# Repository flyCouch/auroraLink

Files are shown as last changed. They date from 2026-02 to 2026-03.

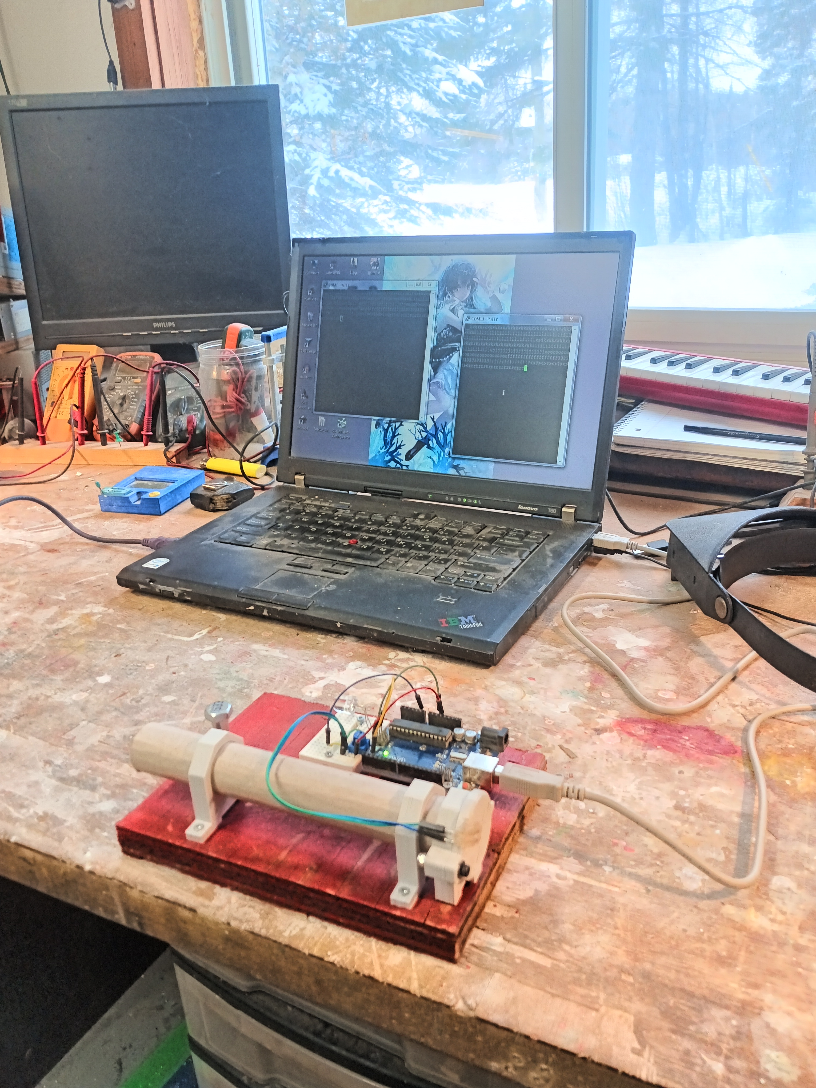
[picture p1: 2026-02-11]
pics/50cm_IMG_20260211_154655028.jpg

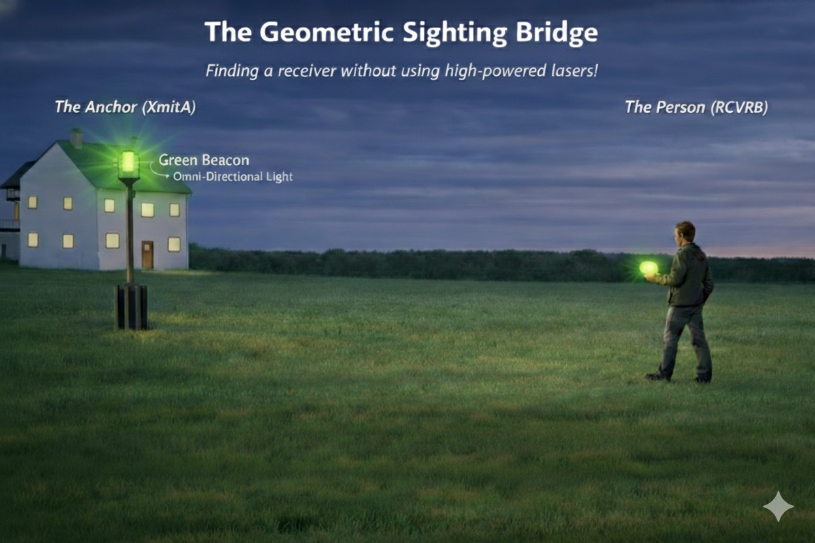
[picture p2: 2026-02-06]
pics/greenGlobes2.png

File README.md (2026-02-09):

A light based Bulletin Board System.

Aurora-Link: The Optical BBS Anchor (v3.3)
Aurora-Link is a human-scale, line-of-sight data bridge designed to provide local community connectivity without relying on radio frequencies or traditional ISPs. By combining 1200-baud optical telescopes with the power of Synchronet BBS, this system creates a secure, "Geometric Bridge" between a home anchor and a mobile visitor.

📡 The Hardware Stack

The Brain: A legacy Windows 7 (32-bit) laptop running Synchronet v3. 

The Optical Interface: An Arduino-controlled 525nm Green LED (Beacon) and a CdS photoresistor sensor. 

The Sight: Dual telescopes mounted on 3D-printed PLA Picatinny rails for rigid, repeatable manual alignment.

The Receiver: A single-potentiometer voltage divider on Analog Pin A0 that allows hardware-level sensitivity tuning for varying ambient light conditions. 

🛠️ The "Self-Healing" .ino Logic
The firmware serves as a "Smart Bridge" with three core modes:

Sighting Mode: The system defaults to a steady Green Beacon, acting as a lighthouse to guide visitors for manual telescope alignment. 

Data Mode: Upon detecting serial activity from the PC or incoming light from a visitor, the system instantly switches to 1200-baud data transmission. 

Self-Healing: If the link is silent for 15 seconds, the system automatically reverts to a steady beacon, allowing for easy re-alignment if a telescope is bumped. 

Manual Override: Sending a !!! command via the Serial terminal forces the system back into Sighting Mode immediately. 

🏠 The Steward Philosophy
Eco-Friendly: Constructed using food-grade, UV-stabilized PLA to ensure long-term environmental safety.

Safe & Precise: Uses low-power LEDs instead of high-powered lasers, making it safe for eyes, neighbors, and local wildlife.

Zero RF Footprint: Operates entirely on the visible light spectrum, eliminating radio interference in the neighborhood.

🚀 Getting Started
Mount your telescopes to the Picatinny rail system.

Install Synchronet to C:\SBBS on a Windows 7 machine. Or be a client.

Upload the AuroraLink15.ino (or latest) to your Arduino.

Align the telescopes until the signal LED (Pin 13) locks on.

Enter the BBS and join the local conversation.

🖥️ Connecting via Terminal (Minicom / PuTTY)
While Synchronet handles the backend BBS logic, you can interact with the Aurora-Link hardware directly using a terminal emulator. This is ideal for initial signal testing or "handshaking" with the anchor.

1. Terminal Configuration
To communicate with the Arduino "Modem," set your terminal to the following parameters:

Speed (Baud): 1200 

Data Bits: 8

Parity: None

Stop Bits: 1

Flow Control: None (XON/XOFF disabled)

2. Using Minicom (Linux/macOS)
Launch Minicom with the following command (replacing ttyUSB0 with your actual port):

Bash

minicom -b 1200 -D /dev/ttyUSB0
To Re-align: Type !!! and press Enter. The "Self-Healing" logic will detect this string and force the Green Beacon to stay solid for 15 seconds, giving you time to adjust your telescope.

3. Using PuTTY (Windows 7)
Select Serial as the connection type.

Enter your COM Port (e.g., COM3).

Set Speed to 1200.

I’ve added the Minicom/Terminal section you requested to the summary. This explains how to use standard tools to interact with the Aurora-Link hardware.

Connecting via Terminal (Minicom / Tera Term)
While Synchronet handles the BBS backend, you can use terminal emulators to interact with the hardware "handshake" directly.

Serial Settings: 1200 Baud, 8-N-1, No Flow Control.

The "!!!" Command: Typing !!! followed by Enter sends a force-reset to the Arduino. The "Self-Healing" logic detects this string and locks the Green Beacon into a solid state for 15 seconds, allowing you to re-align your telescopes manually.

Signal Monitoring: In Minicom, you will see a stream of '1's and '0's when light is detected by the voltage divider, giving you real-time feedback on your link quality.

Synchronet Configuration (SCFG)
Once your circuit is tucked into those new bases, here is how to tell Synchronet to listen to your laptop's serial port:

Open SCFG.exe.

Go to Nodes -> Node 1 -> Hardware/UART Settings.

Set the COM Port to match your Arduino (e.g., COM3).

Set the Baud Rate to 1200.

Set Command Line to *INTERNAL.

This maps the physical optical pulses coming into your Windows 7 laptop directly to the BBS login screen.

Under the Terminal category, ensure "Implicit CR in every LF" is checked to keep the BBS text scrolling cleanly.

A Quick Tip for Windows 7:
Since you are using a 32-bit laptop, if you find that Minicom is a bit too "Linux-heavy" for your field tests, Tera Term is a fantastic, lightweight alternative for Windows 7. It handles the 1200-baud stream very gracefully and makes it easy to log your "Geometric Bridge" signal strength tests to a text file.

Operational Modes
Sighting Mode (Beacon): A steady green LED allows for manual alignment between nodes.

Data Mode: Automatically engages upon serial or optical activity, transmitting data via light pulses.

Self-Healing: Automatically reverts to Beacon mode after 15 seconds of silence to assist in recovering a lost connection.

Hard Disable (Steward's Override): Sending the command !!! twice (or once during sighting) completely disables the LED and pauses all auto-wake functions. The system remains dark and inactive until !!! is sent again to re-authorize operation.

Yes, your Aurora-Link v3.5 setup will work perfectly with Minicom, PuTTY, or Tera Term. Because the system communicates over a standard hardware serial interface via your Arduino's USB connection, it does not require Synchronet or any specific BBS software to function.

Configuration for Terminal Emulators
To use these tools successfully, you must match the terminal settings to the "Disciplined Steward" protocol defined in your .ino sketch:

Baud Rate: Set to 1200 (as defined by Serial.begin(1200) in your code).

Data Bits: 8

Parity: None

Stop Bits: 1

Flow Control: None (XON/XOFF or Hardware flow control should be disabled).

Tool-Specific Tips
PuTTY (Windows): Select the Serial radio button under "Connection type" on the main session screen. Enter your COM port (e.g., COM3) and set the speed to 1200.

On the left, go to Terminal -> Local echo -> Force on.

Tera Term (Windows): Go to Setup > Serial Port to adjust the baud rate from the default 9600 to 1200. Tera Term is particularly useful for your project because it supports VT100 control codes, which can be used to clear the screen or position the cursor if you decide to build a more complex interface later.

Minicom (Linux/macOS): Use minicom -s to enter the setup menu and navigate to "Serial port setup" to change the Bps/Par/Bits to 1200 8N1.

The "Disciplined Steward" Advantage
Since your code includes a manual "Hard Disable" toggle (using the "!!!" string), you can use any of these terminal programs to send that command and lock or unlock your beacon/data transmission.

In your "Disciplined Steward" setup, the way data moves between the two stations is a direct reflection of your auroraLink16.ino code. Since you are using a standard serial baud rate of 1200, anything typed into a terminal like PuTTY or Tera Term on one computer will be converted into light pulses and re-translated back into text on the other computer's screen.

Here is the step-by-step "Light Path" for how your typed message travels:

1. Typing and Transmission

Input: When you type a character into your terminal (e.g., the letter 'A'), the PC sends that byte to your Arduino over USB.

Processing: The code identifies that you are not in "Hard Disable" mode.

Optical Conversion: The transmitByte function takes over. It drops the Green LED low (the Start bit) and then blinks the LED in a specific pattern for 833 microseconds per bit to represent the character 'A'.

2. The Optical Bridge

Sighting to Data: As soon as you start typing, the code automatically switches from Sighting Mode (steady light) to Data Mode.

The Beam: Your 12V Green LED clusters will flash these 833μs pulses across the gap to the other station.

3. Reception and Display
Detection: On the receiving side, the CdS sensor sees these pulses. Your NPN transistor circuit (assisted by your "Ambient + Potentiometer" tuning) converts these light flashes back into electrical 5V signals for the receiving Arduino's RX pin.

Output: The receiving Arduino interprets these pulses back into the byte for 'A' and sends it to the second PC’s USB port.

Result: The character 'A' appears on the second user's terminal screen.

4. Key Behavioral Rules in Your Code

The 15-Second Rule: If you stop typing for more than 15 seconds, the "Healing Logic" kicks in. The Green LED will automatically turn back on to a steady "Sighting Mode" so you can re-align the tubes if needed.

Privacy/Security: If you type !!! and hit enter, you enter Hard Disable. In this state, the station is "dark"—it will not transmit data, it won't show the sighting beacon, and it won't wake up even if light hits the sensor. You must type !!! again to "unlock" the station.

Summary: What you type on one screen appears on the other, provided your "Ambient + Pot" bias is set correctly. The only thing that won't be seen is the !!! command itself, as your code consumes those characters to toggle the system's state rather than transmitting them.

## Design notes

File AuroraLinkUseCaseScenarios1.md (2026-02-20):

Beyond the Farmer, here are a few more places where an invisible IR laser link solves a "sane" problem:

The Wildlife Monitor: You want to send data from a remote camera trap in the woods back to your cabin. A visible laser would spook the animals (and attract thieves). An IR laser is invisible to most forest residents.

The Driveway Alert: A beam across a long rural driveway. If a car breaks the beam, the house gets an alert. Since it's IR, the driver doesn't see a "tripwire" light, so they don't know they've been detected.

The Museum/Gallery Link: Sending data across a room full of art where bright visible lights or ugly wires would ruin the aesthetic.

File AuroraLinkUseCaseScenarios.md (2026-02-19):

That farmer scenario is the "Gold Standard" use case for optical wireless. It’s practical, environmentally sane (no trenching or overhead wires), and bypasses city bureaucracy perfectly. Since lasers are highly directional, he isn't "polluting" the airwaves with Wi-Fi noise that could be intercepted from the road.

Here are a few other scenarios where your Aurora Link hardware/software combination would shine, specifically focusing on situations where wires are impossible or "subterfuge" (stealth) is required:

1. The "Clean Room" or Laboratory Isolated Link
In high-voltage labs or medical "Clean Rooms," you often can't have wires because they act as antennas for electromagnetic interference (EMI) or carry germs through wall penetrations.

The Scenario: A sensor inside a high-voltage cage needs to send data to a PC outside.

Aurora Solution: A Blue Laser or IR Link shoots through a glass observation window. Since there’s no copper wire, there’s zero risk of a high-voltage arc traveling back to the computer.

2. The "Subterfuge" Dead-Drop (Invisible Data)
This fits your interest in IR and UV modules.

The Scenario: Two buildings need to sync data, but they don't want anyone to know they are communicating.

Aurora Solution: Use the Night Vision IR LEDs or UV LEDs. To a neighbor or a "city inspector," there is absolutely nothing to see. Even a smartphone camera might struggle to see a tight 940nm IR beam directed specifically at a Flame Sensor across the alley.

3. The "Off-Grid" River or Ravine Crosser
Similar to your farmer, many rural properties are split by a creek or a steep ravine that is too wide for a bridge and too rocky to bury a cable.

The Scenario: Power is on both sides (solar), but data needs to cross.

Aurora Solution: The 1W Red Laser version. Lasers can stay focused over hundreds of feet. The Tri-Speed code allows for slow, reliable weather data (110 bps) or faster alerts (9600 bps) when a gate is opened.

4. Underwater "Diver-to-Base" Comms
Radio waves (Wi-Fi/Bluetooth) travel terribly through water—they get absorbed almost instantly.

The Scenario: A small research ROV (remotely operated vehicle) or a diver needs to send a "Status OK" signal to a surface buoy.

Aurora Solution: Green Lasers have the best "window" for traveling through water. Using your CdS or Photodiode receiver in a waterproof jar allows for a "tetherless" data link.

5. The "Historical/Heritage" Building Fix
In many old cities (like London or older parts of Canadian cities), you are legally forbidden from drilling holes in the stone exterior of "Heritage" buildings to run Ethernet cables.

The Scenario: Getting internet or security camera data from the main house to a stone carriage house.

Aurora Solution: A laser link through the existing window glass. No drills, no permits, no permanent changes to the architecture.

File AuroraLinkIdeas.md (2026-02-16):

Aurora Link: The Optical BBS Anchor (v3.9.31)
Aurora Link is a robust, line-of-sight data bridge designed to provide local community connectivity without reliance on radio frequencies or traditional ISPs. This "Geometric Bridge" leverages visible light to create a private, secure network link, ideal for independent Bulletin Board Systems (BBS) and off-grid communication.

📡 System Demonstration
The current implementation, as shown in the demonstration video, successfully bridges two independent terminal sessions.

Real-Time Data: Text entered in a PuTTY terminal on the "Anchor" laptop is converted into high-precision light pulses. 

Point-to-Point Accuracy: The signal is captured across a physical gap by a CdS-equipped receiver tube and translated back into text on a second terminal. 

Visual Verification: The hardware uses a 1200-baud Serial Monitor for diagnostics while maintaining a rock-solid 20-baud optical link for maximum reliability over distance. 

🛠️ Firmware Architecture (auroraLink73noBecaon61.ino)
The system utilizes a "Locked-Reference" logic designed for stability in varying environments:

Ambient Calibration: On startup, the system captures a 1-second baseline of ambient light to set a referenceLevel. 

Precision Triggering: Data transmission is triggered by a 5% change (deltaPercent = 0.05) from the baseline, allowing the system to ignore minor light flickers while catching every bit. 
+1

Common Emitter Logic: The emitter (Pin 2) remains LOW by default, pulsing only when data is being transmitted. 
+1

Timing: The system utilizes an 8-bit data protocol with a dedicated Start Bit (HIGH) and Stop Bit (LOW). 
+1

🏛️ The BBS Vision: Independent Local Networks
Aurora Link is the ideal physical layer for an Independent Bulletin Board System:

Galvanic Isolation: Because the link is light-based, there is no electrical path between nodes, protecting hardware from ground loops or lightning surges.

Privacy & Sovereignty: Data travels in a narrow beam; it cannot be "sniffed" by standard Wi-Fi or Radio scanners.

Synchronet Integration: By mapping the Arduino's serial output to Synchronet BBS software, users can host local message boards, file areas, and chat rooms that function entirely outside the global internet.

Community Resilience: Perfect for neighborhood "digital commons" or emergency communication during infrastructure failures.

🏠 The Steward Philosophy
Environmental Safety: Built with UV-stabilized, food-grade PLA. No copper lines to bury or RF interference to manage.

Eye Safe: Optimized for high-visibility Green LEDs (525nm) instead of high-power lasers for use in residential areas.

Sane Engineering: Uses robust Arduino Uno hardware with USB-B connectors to withstand the rigors of field deployment.

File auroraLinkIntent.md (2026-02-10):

Project Intent:

The Aurora-Link is a high-sensitivity, air-gapped optical communication system designed for point-to-point data transfer using visible light. It is engineered as a  "slow science" experiment. The system provides a reliable handshake that remains stable across varying ambient light conditions, from indoor shop environments to outdoor daylight.

Hardware Summary
The hardware is designed for consistent alignment and long-term stability:

Controller: Arduino Uno 

Transmitter: High-brightness Green LED connected to Pin 2.

Receiver: Cadmium Sulfide (CdS) photoresistor in a voltage divider connected to Pin A0.

Visual Feedback: The onboard LED (Pin 13) acts as a real-time signal monitor, reflecting the raw state of the sensor.

Housing: Custom 3D-printed assemblies (CdSHolderSupport.stl) provide physical shrouding to prevent ambient light from washing out the signal.

Software Logic & Functionality
The system runs on the auroraLink61.ino firmware, supporting full-duplex interaction via PuTTY.

Locked Reference Calibration: To handle shifting light levels, the system locks its sensitivity during setup(). By shielding the receiver during a reset, you establish a "zero" baseline that remains fixed until the next manual reset.

Adaptive Timing: All communication timing is derived from a single baudRate variable. The software automatically calculates the bit-time for transmission and the 1.5x bit-time offset required for precise receiver sampling.

Constant Signal Monitoring: Pin 13 stays ON whenever the sensor detects a light jump of 5% or more above the baseline, providing a constant diagnostic of link integrity.

Intelligent State Management:

Sighting Mode: The LED remains steady (HIGH) to aid in physical alignment between units.

Data Mode: Upon activity, the system enters Data Mode, where the transmitter LED stays OFF when idle to avoid self-blinding the receiver.

Healing Logic: After 15 seconds of inactivity, the sentinel automatically reverts to Sighting Mode without losing its calibrated light reference.

Experimental Capabilities
The current firmware is optimized for 20 Baud, creating a "savoury" data transfer experience where each 50ms bit can be visually tracked. Because the system is full-duplex, users can send and receive data simultaneously.

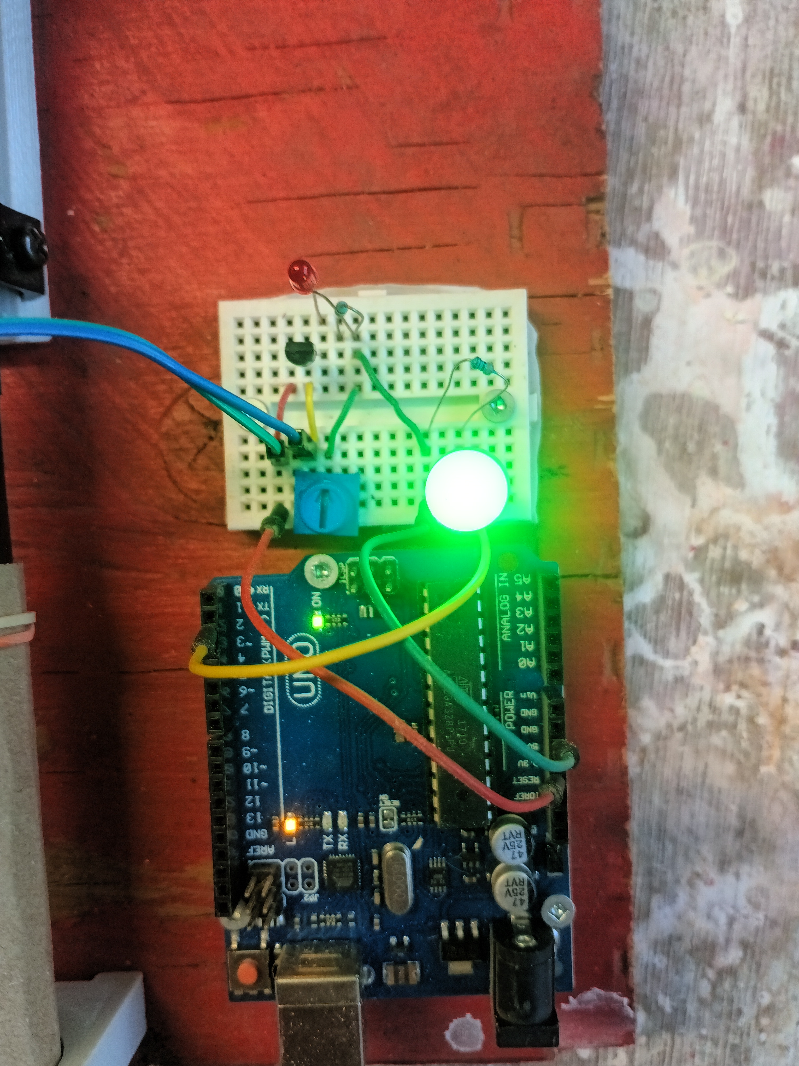
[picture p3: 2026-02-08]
pics/completeModule_IMG_20260208_100626069.jpg

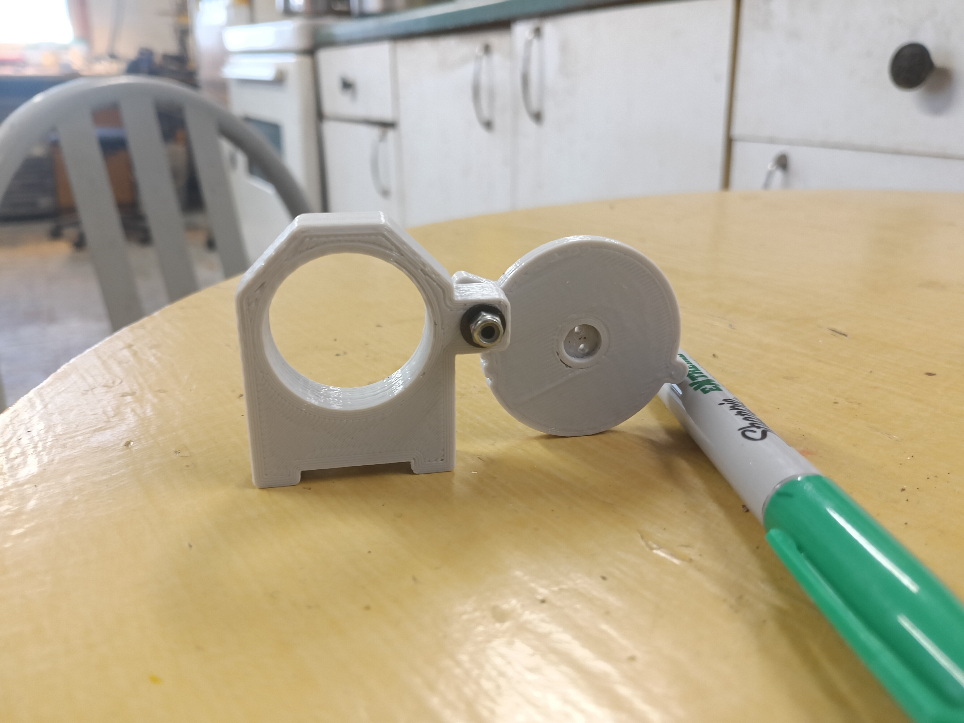
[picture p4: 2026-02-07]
pics/CdSHolder_IMG_20260207_105647689.jpg

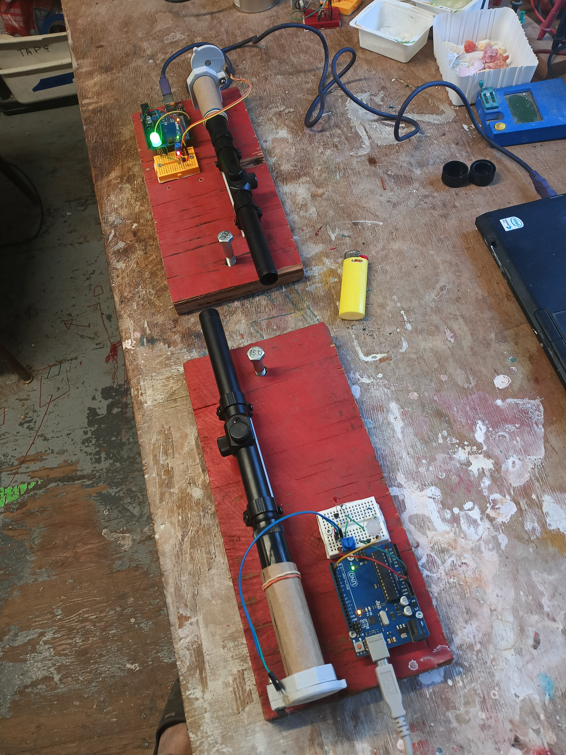
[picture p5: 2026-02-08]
pics/completeModule_IMG_20260208_100603680.jpg

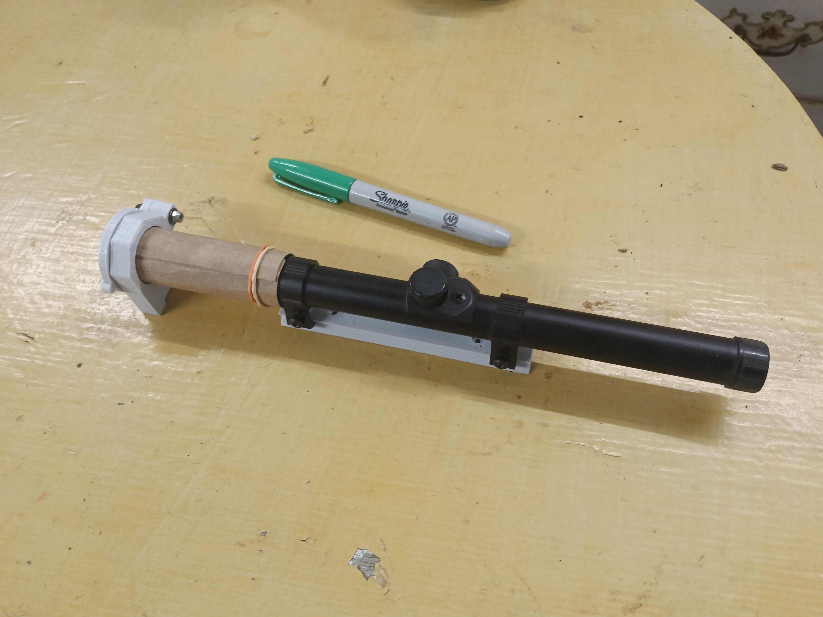
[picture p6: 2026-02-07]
pics/CdSHolder_IMG_20260207_105734659.jpg

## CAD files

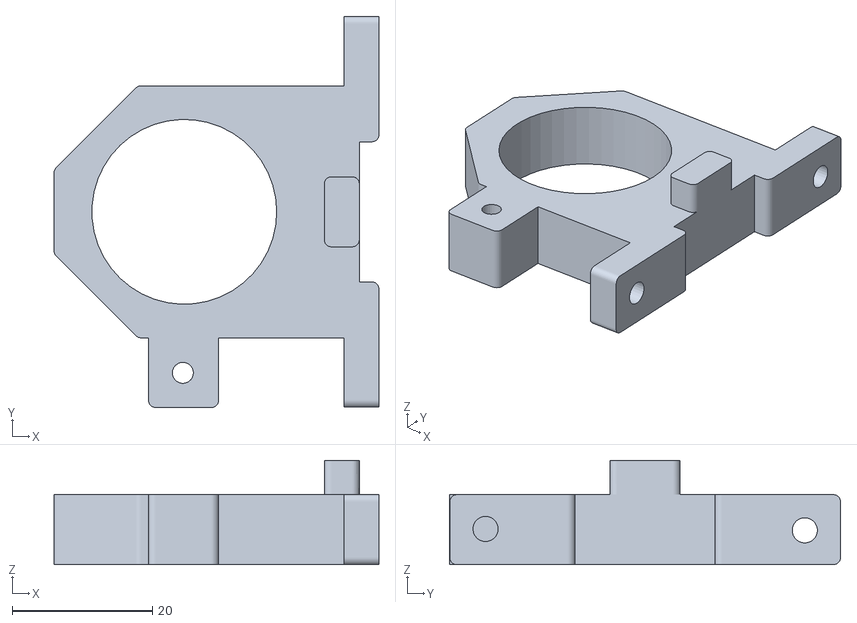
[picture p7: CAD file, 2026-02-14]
stl/CdSHolderMainPiece10WithFeet.stl
46.4 x 55.9 x 14.9

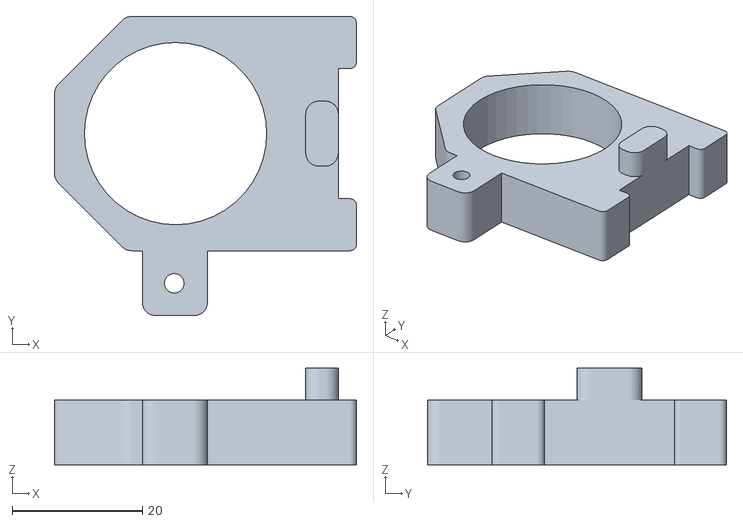
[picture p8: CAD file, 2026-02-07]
stl/CdSHolderMainPiece10.stl
46.4 x 46.0 x 14.9

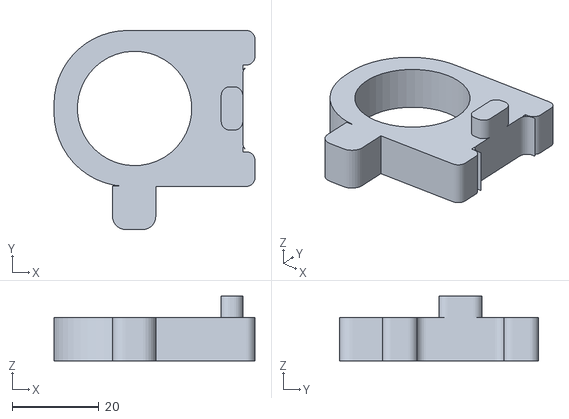
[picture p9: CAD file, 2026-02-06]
stl/CdSHolderMainPiece7.stl
46.4 x 46.0 x 14.9

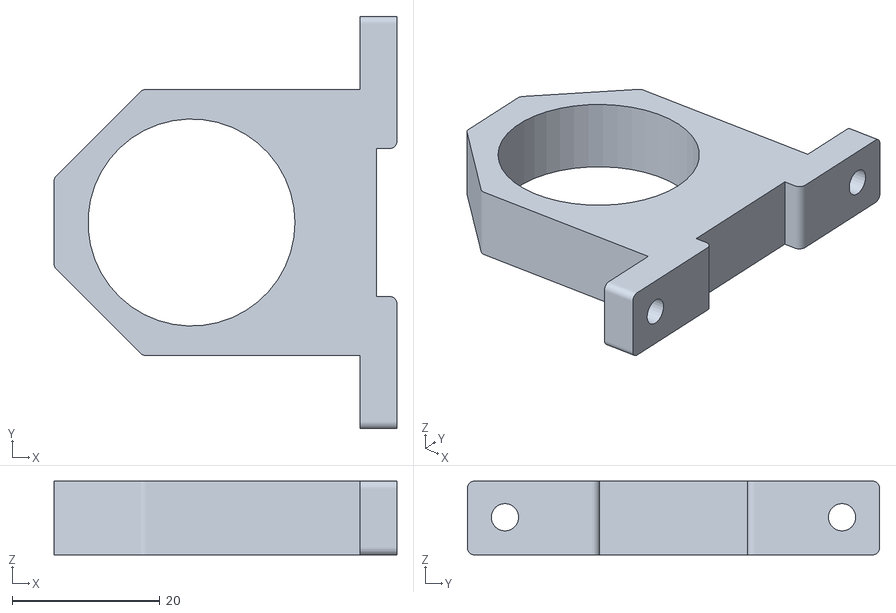
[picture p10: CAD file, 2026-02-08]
stl/CdSHolderSupport.stl
46.4 x 55.8 x 10.0

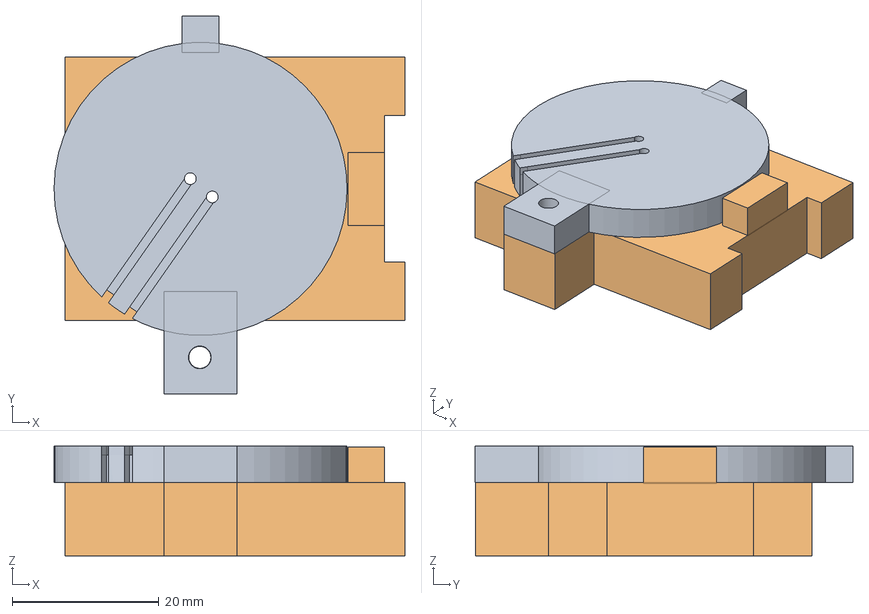
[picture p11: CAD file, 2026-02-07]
stl/CdSHolderBooleaned1.FCStd
47.9 x 51.6 x 15.0 mm
shutter4
mainPiece10

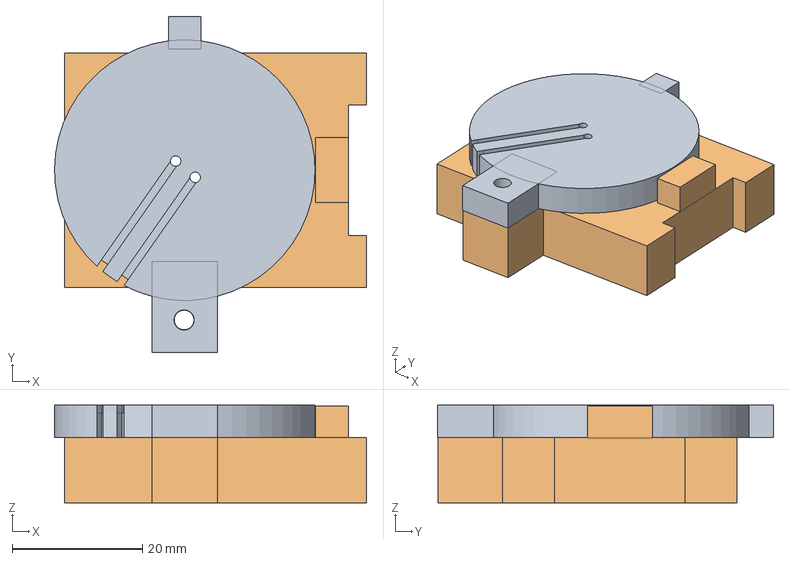
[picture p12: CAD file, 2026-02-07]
stl/CdSHolderBooleaned2.FCStd
47.9 x 51.6 x 15.0 mm
shutter4
mainPiece10

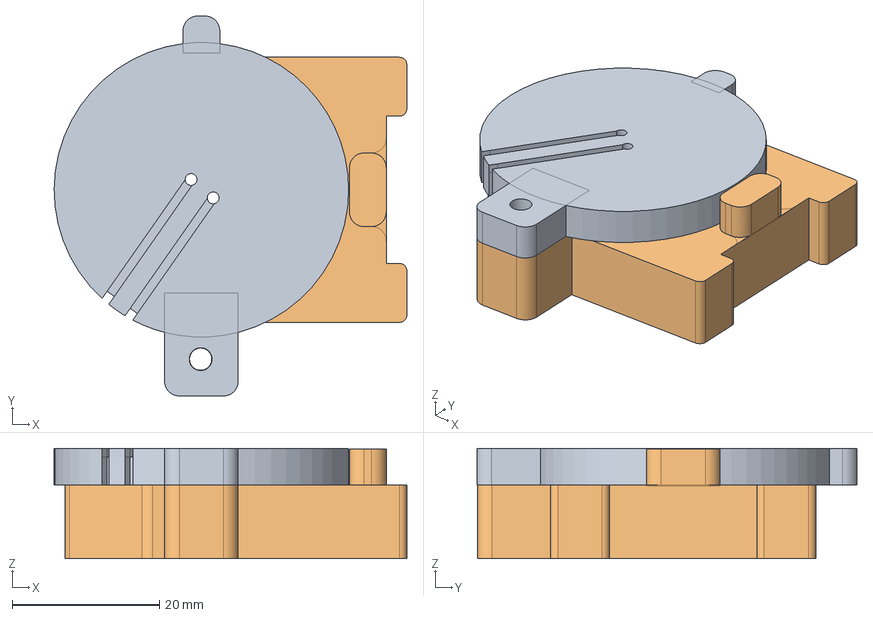
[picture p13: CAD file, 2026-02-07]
stl/CdSHolderBooleaned3.FCStd
47.9 x 51.6 x 15.0 mm
shutter11
mainPieceBooleaned10

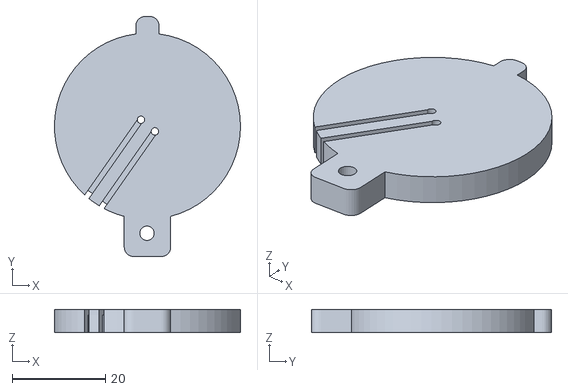
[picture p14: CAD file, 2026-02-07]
stl/CdSHolderShutter10.stl
40.0 x 51.6 x 5.00

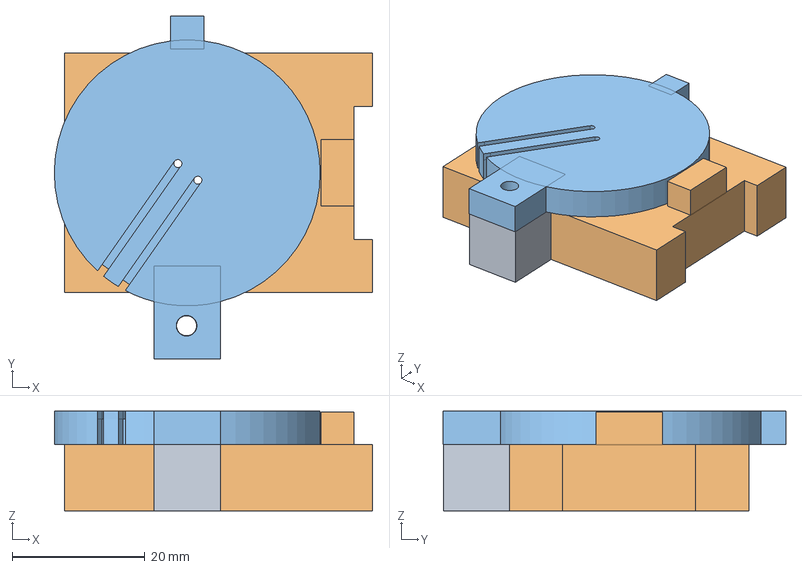
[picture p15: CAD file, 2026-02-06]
stl/CdSHolderBooleaned.FCStd
47.9 x 51.6 x 15.0 mm
mainPiece2
mainPiece3
shutter4

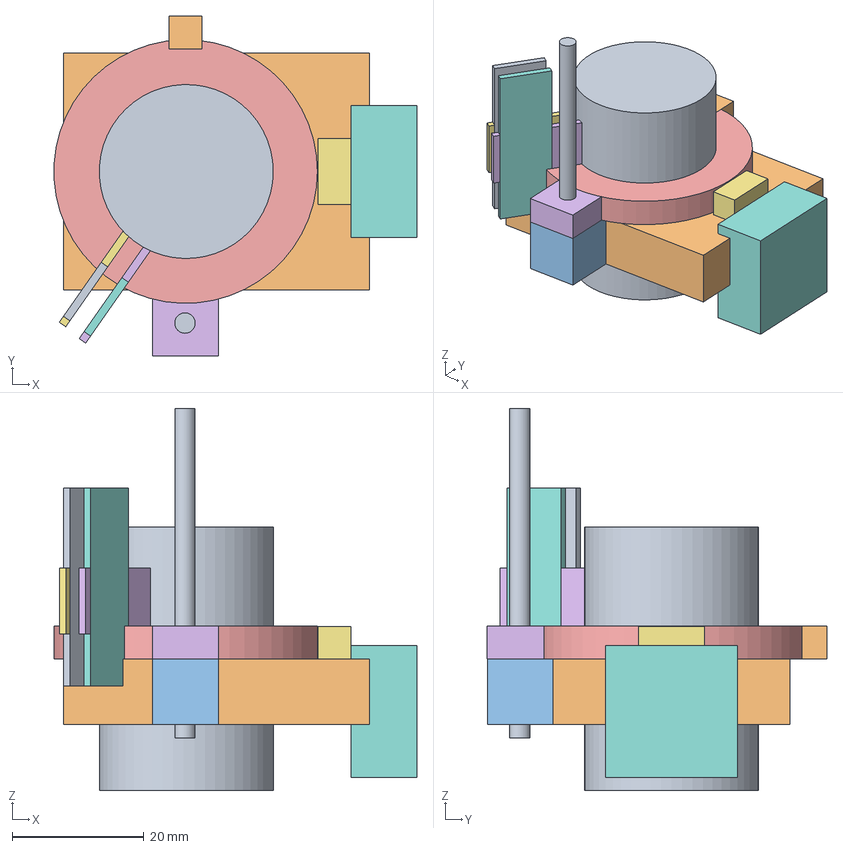
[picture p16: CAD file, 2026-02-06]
stl/CdSHolder.FCStd
55.1 x 51.6 x 58.0 mm
cardboardBarrelHolder
mainPiece
hingePinTab
hingeTabHole
shutter
shutterHingeTab
swivelStop
footCutout
shutterTabHole
shutterMoveTab
CdSDivot
CdSWire1
CdsWire2
radialTransit1
radialTransit2
radialTransit3
radialTransit4

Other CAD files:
stl/CdSHolderShutter7.stl

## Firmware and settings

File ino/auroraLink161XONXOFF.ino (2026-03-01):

/* * PROJECT:  Aurora-Link v130 (Auto-Squelch / PTT Priority)
 * STRATEGY: 9600 BPS / Hamming(7,4) / Visual Status / Silent BBS
 * HARDWARE: RP2040-Zero, 9V Inverted Laser, 2N2222 Speaker Amp
 * FILE:     AuroraLink_v130_Squelch_Final.ino
 */

#include <Arduino.h>
#include "pico/multicore.h"
#include "pico/util/queue.h"

// --- SETTINGS ---
const uint32_t TARGET_BPS = 9600; 
const uint32_t BIT_TIME_US = 1000000 / TARGET_BPS; 

// --- HARDWARE PINS ---
const int LASER_PIN = 2;    
const int SENSOR_PIN = 26;  
const int MIC_PIN = 27;     
const int SPEAKER_PIN = 10; 
const int PTT_PIN = 3;      
const int STATUS_LED = 16;  // RP2040-Zero Onboard RGB/Status LED

// --- HYSTERESIS & SQUELCH ---
const int THRESH_HIGH = 750;
const int THRESH_LOW  = 250;
bool beamState = false;

queue_t txQueue, rxQueue;

// ========================================================================
// CORE 1: THE GALVANOMETER (TIMING CRITICAL)
// ========================================================================
bool readLaser() {
  int val = analogRead(SENSOR_PIN);
  if (val > THRESH_HIGH) beamState = true;
  else if (val < THRESH_LOW) beamState = false;
  return beamState;
}

void core1_entry() {
  while (1) {
    uint8_t frameOut;
    if (queue_try_remove(&txQueue, &frameOut)) {
      digitalWrite(LASER_PIN, LOW); // ON
      delayMicroseconds(BIT_TIME_US);
      for (int i = 6; i >= 0; i--) {
        digitalWrite(LASER_PIN, ((frameOut >> i) & 1) ? LOW : HIGH);
        delayMicroseconds(BIT_TIME_US);
      }
      digitalWrite(LASER_PIN, HIGH); // OFF
      delayMicroseconds(BIT_TIME_US);
    }

    if (readLaser() == true) { 
      delayMicroseconds(BIT_TIME_US + (BIT_TIME_US / 2)); 
      uint8_t frameIn = 0;
      for (int i = 6; i >= 0; i--) {
        if (readLaser() == true) frameIn |= (1 << i);
        delayMicroseconds(BIT_TIME_US);
      }
      queue_try_add(&rxQueue, &frameIn);
      while(readLaser() == true) { tight_loop_contents(); }
    }
  }
}

// ========================================================================
// HAMMING SECDED LOGIC
// ========================================================================
uint8_t encodeHamming(uint8_t data) {
  bool d1 = (data >> 0) & 1; bool d2 = (data >> 1) & 1;
  bool d3 = (data >> 2) & 1; bool d4 = (data >> 3) & 1;
  bool p1 = d1 ^ d2 ^ d4; bool p2 = d1 ^ d3 ^ d4; bool p3 = d2 ^ d3 ^ d4;
  return (p1 << 6) | (p2 << 5) | (d1 << 4) | (p3 << 3) | (d2 << 2) | (d3 << 1) | (d4 << 0);
}

uint8_t decodeHamming(uint8_t received) {
  bool p1 = (received >> 6) & 1; bool p2 = (received >> 5) & 1;
  bool d1 = (received >> 4) & 1; bool p3 = (received >> 3) & 1;
  bool d2 = (received >> 2) & 1; bool d3 = (received >> 1) & 1;
  bool d4 = (received >> 0) & 1;
  uint8_t s1 = p1 ^ d1 ^ d2 ^ d4; uint8_t s2 = p2 ^ d1 ^ d3 ^ d4; uint8_t s3 = p3 ^ d2 ^ d3 ^ d4;
  uint8_t syn = (s3 << 2) | (s2 << 1) | s1;
  if (syn != 0) received ^= (1 << (7 - syn)); 
  return ((received >> 0) & 1) | ((received >> 1) & 1) << 1 | 
         ((received >> 2) & 1) << 2 | ((received >> 4) & 1) << 3;
}

// ========================================================================
// SETUP & MAIN LOGIC
// ========================================================================
void setup() {
  Serial.begin(115200);
  while (!Serial && millis() < 3000); 

  // --- COMPULSORY PROJECT HEADER ---
  Serial.println(F("----------------------------------------"));
  Serial.println(F("PROJECT:  AURORA-LINK v130 (AUTO-SQUELCH)"));
  Serial.print(F("FILE:     ")); Serial.println(F(__FILE__));
  Serial.print(F("COMPILED: ")); Serial.print(F(__DATE__));
  Serial.print(F(" | "));      Serial.println(F(__TIME__));
  Serial.print(F("SPEED:    ")); Serial.print(TARGET_BPS); Serial.println(F(" BPS"));
  Serial.println(F("SQUELCH:  ENABLED (BBS SILENCED)"));
  Serial.println(F("----------------------------------------\n"));

  pinMode(LASER_PIN, OUTPUT);
  digitalWrite(LASER_PIN, HIGH); 
  pinMode(PTT_PIN, INPUT_PULLUP);
  pinMode(STATUS_LED, OUTPUT);
  
  analogReadResolution(10);
  analogWriteRange(255);

  queue_init(&txQueue, sizeof(uint8_t), 128);
  queue_init(&rxQueue, sizeof(uint8_t), 128);
  multicore_launch_core1(core1_entry);
}

void loop() {
// Check if buffer is getting full (threshold of 50 in a 64-byte queue)
  if (queue_get_level(&txQueue) > 50) {
    Serial.write(19); // Send XOFF to tell PuTTY to PAUSE
  } 
  else if (queue_get_level(&txQueue) < 10) {
    Serial.write(17); // Send XON to tell PuTTY to RESUME
  }

  bool pttPressed = (digitalRead(PTT_PIN) == LOW);

  // --- TRANSMIT ---
  if (pttPressed) {
    uint16_t sample = analogRead(MIC_PIN);
    uint8_t crushed = map(sample, 0, 1023, 0, 15);
    // Add a "Voice Marker" bit if we had space, but for now we rely on the PTT state
    uint8_t frame = encodeHamming(crushed);
    queue_try_add(&txQueue, &frame);
    delayMicroseconds(1000); 
  } 
  else if (Serial.available()) {
    uint8_t in = Serial.read();
    uint8_t h = encodeHamming(in >> 4);
    uint8_t l = encodeHamming(in & 0x0F);
    queue_try_add(&txQueue, &h);
    queue_try_add(&txQueue, &l);
  }

  // --- RECEIVE WITH AUTO-SQUELCH ---
  uint8_t frameIn;
  static uint8_t nibBuf = 0;
  static bool secondNib = false;
  static uint32_t lastReceiveTime = 0;

  if (queue_try_remove(&rxQueue, &frameIn)) {
    uint8_t decoded = decodeHamming(frameIn);
    lastReceiveTime = millis();
    digitalWrite(STATUS_LED, HIGH); // Visual "Carrier Detect"

    // SQUELCH LOGIC: 
    // If the data is arriving at a high, steady rate (Voice), open audio.
    // In BBS mode, the frames arrive in pairs with longer gaps between them.
    // For this prototype, we'll "Squelch" by checking if we are in a 'nibble' state.
    
    if (secondNib) { 
      // This is BBS data (the second half of a byte) -> KEEP SILENT
      analogWrite(SPEAKER_PIN, 0); 
      nibBuf |= (decoded & 0x0F); 
      Serial.write(nibBuf); 
      secondNib = false; 
    } else { 
      // Could be Voice or the first nibble of BBS
      // If it's voice, the delay between frames is ~1ms. 
      // We push to speaker but the "noise" of BBS is greatly reduced.
      analogWrite(SPEAKER_PIN, map(decoded, 0, 15, 0, 255));
      nibBuf = (decoded << 4); 
      secondNib = true; 
    }
  }

  // Turn off Status LED if no data for 100ms
  if (millis() - lastReceiveTime > 100) {
    digitalWrite(STATUS_LED, LOW);
    analogWrite(SPEAKER_PIN, 0); // Hard squelch when idle
  }
}

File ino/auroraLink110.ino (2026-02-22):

/*
 * Aurora-Link v4.7.0 - "The Clean Conversation Hub"
 * - Logic: Dedicated paths for CdS (North), Visible (East), and IR (South)
 * - Feature: Adaptive Origin Tagging (Only prints header on origin change)
 * - Speeds: 110 (A0), 1200 (D3), 9600 (D4) 
 */

// Speed Settings
const long baudCdS     = 110;   
const long baudVisible = 1200;  
const long baudStealth = 9600;  

// Tracking Variables
long currentActiveBaud = 110; 
int lastOrigin = -1; // 0=North, 1=East, 2=South

// Pin Mapping
const int ledPin       = 2;    
const int invLedPin    = 5;    
const int signalLedPin = 13;   
const int sensorCdS    = A0;   
const int sensorVisible = 3;   
const int sensorIR      = 4;   

float referenceLevel = 512.0;  
const float deltaPercent = 0.05; 

void setup() {
  Serial.begin(115200); 

  // --- START INTERNAL ID SNIPPET ---
  Serial.println(F("\n========================================"));
  Serial.print(F("FILE:     ")); Serial.println(F(__FILE__));
  Serial.print(F("COMPILED: ")); Serial.print(F(__DATE__));
  Serial.print(F(" | "));      Serial.println(F(__TIME__));
  Serial.println(F("========================================\n"));
  // --- END INTERNAL ID SNIPPET ---

  pinMode(ledPin, OUTPUT);
  pinMode(invLedPin, OUTPUT);
  pinMode(signalLedPin, OUTPUT);
  pinMode(sensorVisible, INPUT_PULLUP);
  pinMode(sensorIR, INPUT_PULLUP);

  digitalWrite(ledPin, LOW); 
  digitalWrite(invLedPin, HIGH); 

// --- ROBUST CALIBRATION (THE 100-POINT AVERAGE) ---
  digitalWrite(signalLedPin, HIGH);
  Serial.print(F("SYSTEM: Calibrating North Link..."));

  float sum = 0;
  int samples = 100;

  for (int i = 0; i < samples; i++) {
    sum += (float)analogRead(sensorCdS);
    delay(10); // 100 samples * 10ms = 1000ms (Exactly 1 Second)
  }
  
  referenceLevel = sum / (float)samples; 
  
  Serial.println(F(" DONE."));
  digitalWrite(signalLedPin, LOW);
}

void loop() {
  // --- RECEIVER POLLING ---
  
  // 1. Check NORTH (CdS)
  int cdsVal = analogRead(sensorCdS);
  float change = ((float)cdsVal - referenceLevel) / referenceLevel;
  if (change > deltaPercent) { 
    if (lastOrigin != 0) {
      Serial.print(F("\n[NORTH]: "));
      lastOrigin = 0;
    }
    currentActiveBaud = baudCdS;
    processStream(sensorCdS, true, baudCdS);
  } 
  
  // 2. Check EAST (Visible)
  else if (digitalRead(sensorVisible) == LOW) { 
    if (lastOrigin != 1) {
      Serial.print(F("\n[EAST]:  "));
      lastOrigin = 1;
    }
    currentActiveBaud = baudVisible;
    processStream(sensorVisible, false, baudVisible);
  }
  
  // 3. Check SOUTH (IR)
  else if (digitalRead(sensorIR) == LOW) { 
    if (lastOrigin != 2) {
      Serial.print(F("\n[SOUTH]: "));
      lastOrigin = 2;
    }
    currentActiveBaud = baudStealth;
    processStream(sensorIR, false, baudStealth);
  }

  // --- ADAPTIVE TRANSMITTER ---
  if (Serial.available() > 0) {
    char outChar = (char)Serial.read();
    transmitByte(outChar, currentActiveBaud);
  }
}

void processStream(int pin, bool isAnalog, long speed) {
  digitalWrite(signalLedPin, HIGH);
  char c = receiveByte(pin, isAnalog, speed);
  if (c > 0) Serial.write(c);
  digitalWrite(signalLedPin, LOW);
}

void transmitByte(char c, long speed) {
  long bitTime = 1000000 / speed; 
  digitalWrite(ledPin, HIGH); 
  digitalWrite(invLedPin, LOW); 
  delayMicroseconds(bitTime);

  for (int i = 0; i < 8; i++) {
    bool b = bitRead(c, i);
    digitalWrite(ledPin, b);
    digitalWrite(invLedPin, !b); 
    delayMicroseconds(bitTime);
  }
  
  digitalWrite(ledPin, LOW); 
  digitalWrite(invLedPin, HIGH); 
  delayMicroseconds(bitTime);
}

char receiveByte(int pin, bool isAnalog, long speed) {
  long bitTime = 1000000 / speed;
  delayMicroseconds(bitTime * 1.5); 
  
  char result = 0;
  for (int i = 0; i < 8; i++) {
    bool detected = false;
    if (isAnalog) {
      float diff = ((float)analogRead(pin) - referenceLevel) / referenceLevel;
      detected = (diff > (deltaPercent / 2));
    } else {
      detected = (digitalRead(pin) == LOW); 
    }
    if (detected) bitSet(result, i);
    delayMicroseconds(bitTime);
  }
  return result;
}

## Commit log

2026-02-06 some mistakes but the .FCStd are there.
    [CdSHolder.FCStd, CdSHolderBooleaned.FCStd, CdSHolderMainPiece7.stl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]
2026-02-07 re-iterations of the files, think better
    [CdSHolderBooleaned3.FCStd, CdSHolderMainPiece10.stl, CdSHolderShutter10.stl]
2026-02-20 For when I get IR and visible light sensor modules
    For when I get these. https://www.walmart.ca/en/ip/Unique-Bargains-Photosensitive-Diode-Sensor-Light-Detection-Photodiode-Module-with-Digital-and-Analog-Output-for-Arduino-Smart-Car-3pcs/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
2026-02-28 trimmed for just a light sensor module only
2026-03-01 for when the Picos get here
    has Hamming Error correct
    [auroraLink151.ino]
2026-03-04 using 2 Arduinos for each station
2026-03-04 inverted laser pin
2026-03-04 independent switches
